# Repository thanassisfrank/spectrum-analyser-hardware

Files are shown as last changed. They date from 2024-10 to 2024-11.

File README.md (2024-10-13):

# 5.8GHz Spectrum analyser hardware

This is an open source project to create a device for analysing the 5.8GHz radio band using the RX5808 analog receiver module and the ESP32-C3 Zero. This repository holds the hardware for the device created with KiCad. For an overview of the firmware, please see *firmware repo*.

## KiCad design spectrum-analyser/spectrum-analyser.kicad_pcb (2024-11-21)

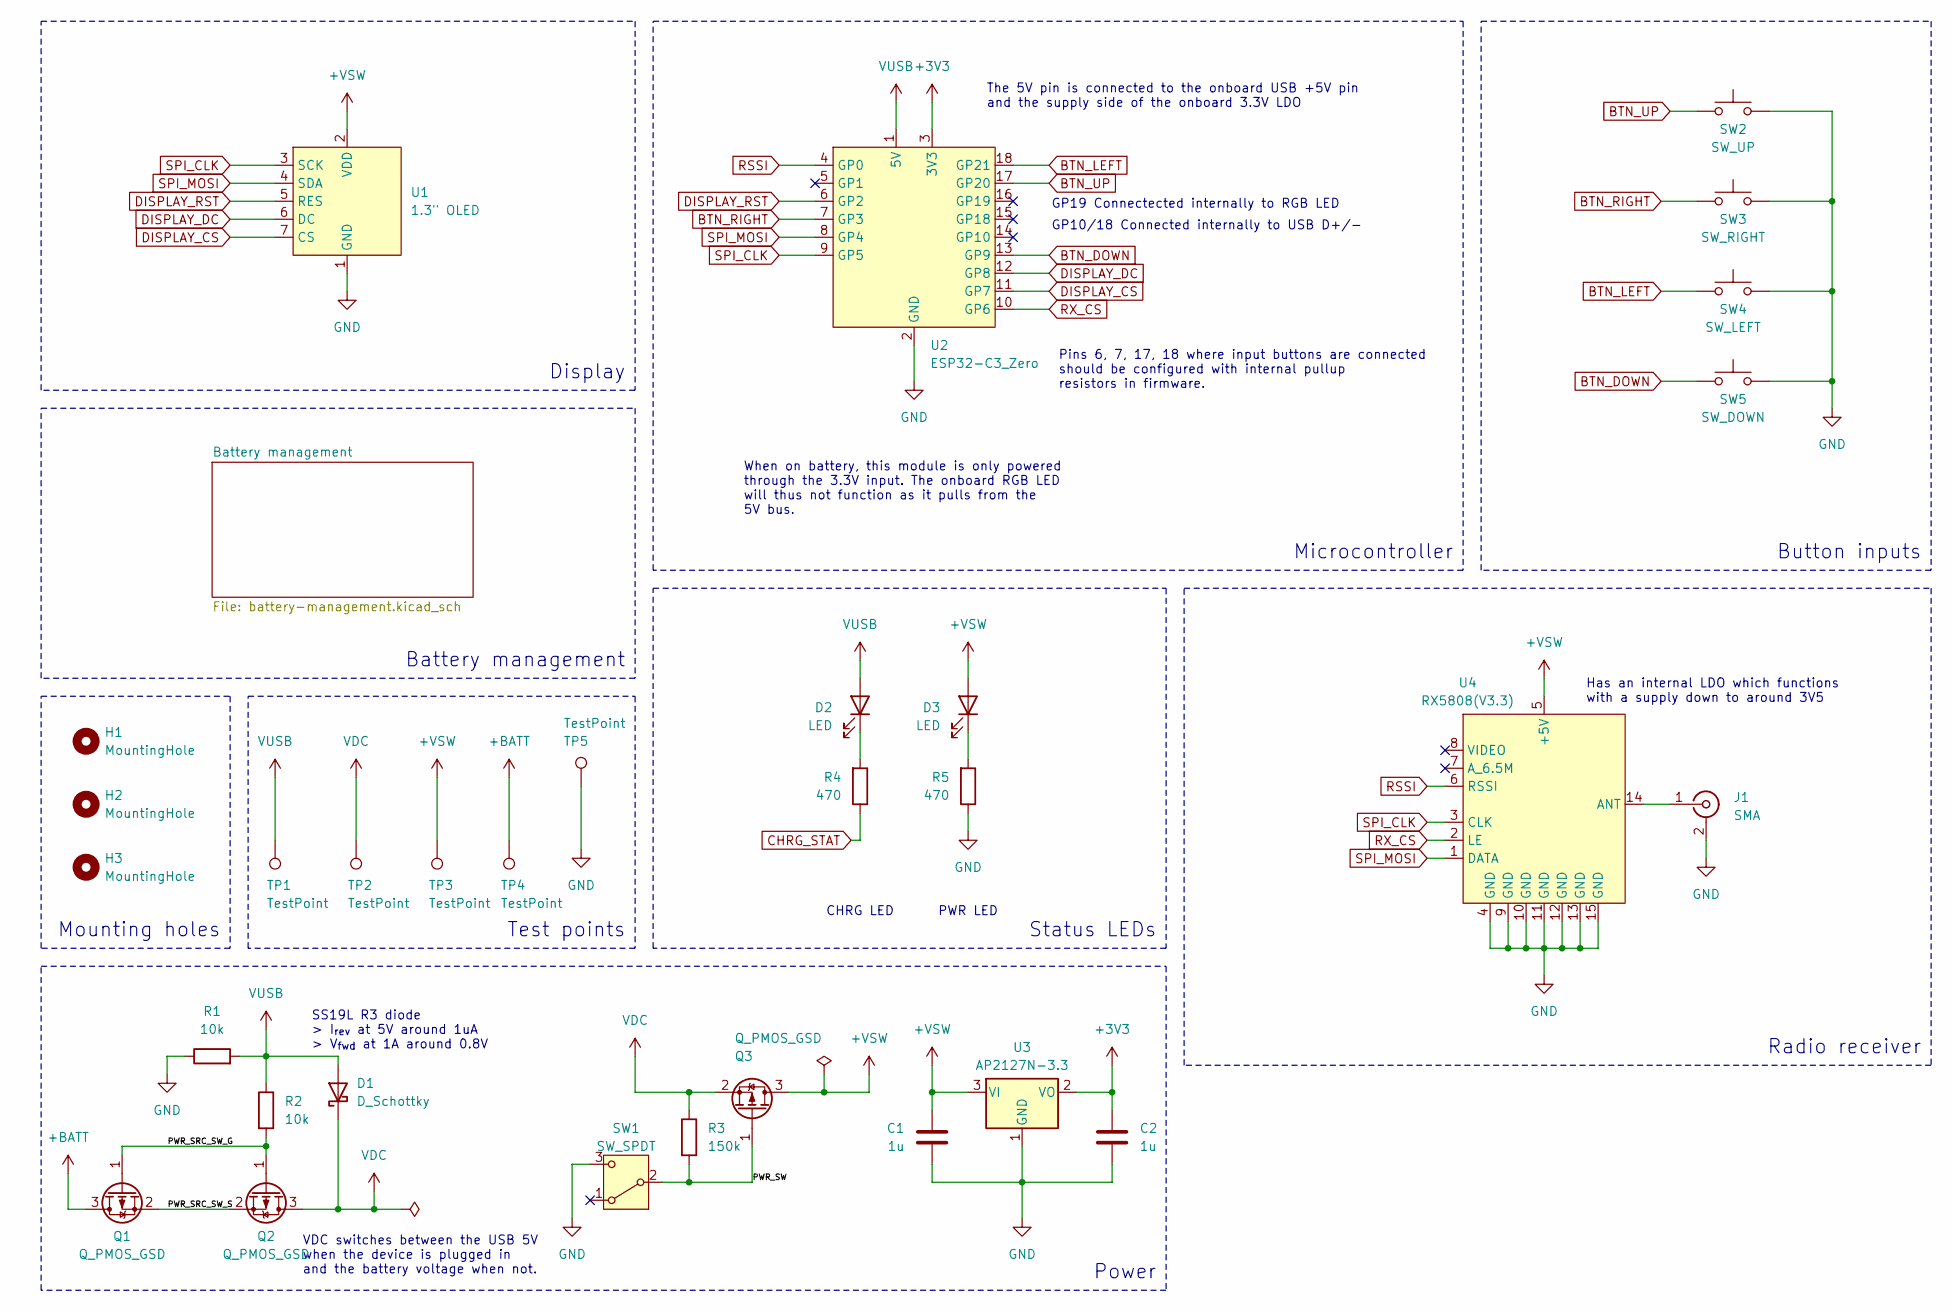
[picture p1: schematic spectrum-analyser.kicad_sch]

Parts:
C1, C2: 1u; C_0603_1608Metric_Pad1.08x0.95mm_HandSolder
D1: D_Schottky; D_SMA_Handsoldering
D2, D3: LED; LED_0603_1608Metric_Pad1.05x0.95mm_HandSolder
H1, H2, H3: MountingHole; MountingHole_3.2mm_M3_ISO7380
J1: SMA; SMA_Samtec_SMA-J-P-H-ST-EM1_EdgeMount
Q1, Q2, Q3: Q_PMOS_GSD; SOT-23
R1, R2: 10k; R_0603_1608Metric_Pad0.98x0.95mm_HandSolder
R3: 150k; R_0603_1608Metric_Pad0.98x0.95mm_HandSolder
R4, R5: 470; R_0603_1608Metric_Pad0.98x0.95mm_HandSolder
SW1: SW_SPDT; SW_SPDT_TEC_1825232-1
SW2: SW_UP; SW_PUSH_ADAFRUIT_SMALL
SW3: SW_RIGHT; SW_PUSH_ADAFRUIT_SMALL
SW4: SW_LEFT; SW_PUSH_ADAFRUIT_SMALL
SW5: SW_DOWN; SW_PUSH_ADAFRUIT_SMALL
TP1, TP2, TP3, TP4: TestPoint; TestPoint_Pad_D2.0mm
TP5: TestPoint; TestPoint_THTPad_D2.0mm_Drill1.0mm
U1: 1.3" OLED; 1.30 OLED
U2: ESP32-C3_Zero
U3: AP2127N-3.3; SOT-23
U4: RX5808(V3.3)

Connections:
+3V3: C2.1, U2.3 (3V3), U3.2 (VO)
+BATT: Q1.3 (D), TP4.1; also elsewhere on the board
+VSW: C1.1, D3.2 (A), Q3.3 (D), TP3.1, U1.2 (VDD), U3.3 (VI), U4.5 (+5V)
/PWR_SRC_SW_G: Q1.1 (G), Q2.1 (G), R2.2
/PWR_SRC_SW_S: Q1.2 (S), Q2.2 (S)
/PWR_SW: Q3.1 (G), R3.2, SW1.2 (B)
BTN_DOWN: SW5.1, U2.13 (GP9)
BTN_LEFT: SW4.1, U2.18 (GP21)
BTN_RIGHT: SW3.1, U2.7 (GP3)
BTN_UP: SW2.1, U2.17 (GP20)
CHRG_STAT: R4.1; also elsewhere on the board
DISPLAY_CS: U1.7 (CS), U2.11 (GP7)
DISPLAY_DC: U1.6 (DC), U2.12 (GP8)
DISPLAY_RST: U1.5 (RES), U2.6 (GP2)
GND: C1.2, C2.2, J1.2 (Ext), R1.1, R5.1, SW1.3 (C), SW2.2, SW3.2, SW4.2, SW5.2, TP5.1, U1.1 (GND), U2.2 (GND), U3.1 (GND), U4.4 (GND), U4.9 (GND), U4.10 (GND), U4.11 (GND), U4.12 (GND), U4.13 (GND), U4.15 (GND); also elsewhere on the board
unnamed: D2.1 (K), R4.2
unnamed: D3.1 (K), R5.2
unnamed: J1.1 (In), U4.14 (ANT)
RSSI: U2.4 (GP0), U4.6 (RSSI)
RX_CS: U2.10 (GP6), U4.2 (LE)
SPI_CLK: U1.3 (SCK), U2.9 (GP5), U4.3 (CLK)
SPI_MOSI: U1.4 (SDA), U2.8 (GP4), U4.1 (DATA)
VDC: D1.1 (K), Q2.3 (D), Q3.2 (S), R3.1, TP2.1
VUSB: D1.2 (A), D2.2 (A), R1.2, R2.1, TP1.1, U2.1 (5V); also elsewhere on the board

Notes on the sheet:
VDC switches between the USB 5V when the device is plugged in and the battery voltage when not.
Power
PWR LED
GP10/18 Connected internally to USB D+/-
Pins 6, 7, 17, 18 where input buttons are connected should be configured with internal pullup resistors in firmware.
When on battery, this module is only powered through the 3.3V input. The onboard RGB LED will thus not function as it pulls from the 5V bus.
Button inputs
Status LEDs
Has an internal LDO which functions with a supply down to around 3V5
Battery management
GP19 Connectected internally to RGB LED
Radio receiver
Test points
Microcontroller
The 5V pin is connected to the onboard USB +5V pin and the supply side of the onboard 3.3V LDO
SS19L R3 diode > I_{rev} at 5V around 1uA > V_{fwd} at 1A around 0.8V
CHRG LED
Mounting holes
Display

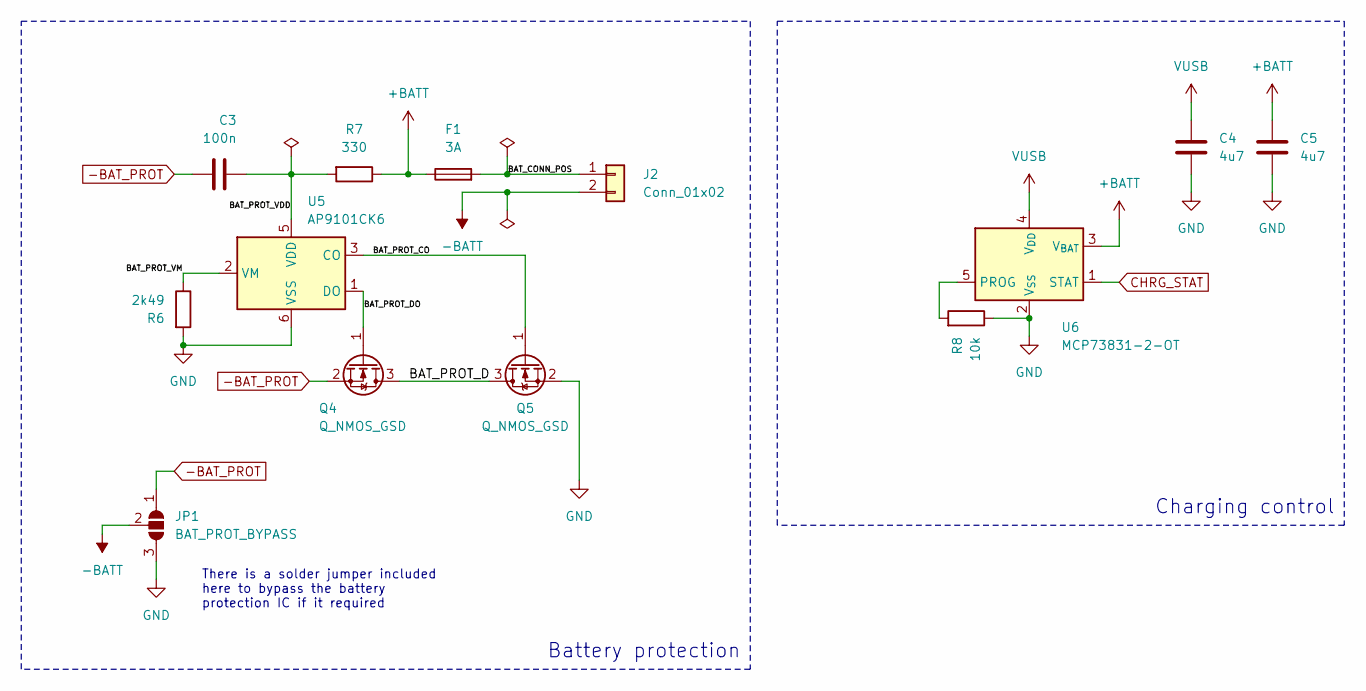
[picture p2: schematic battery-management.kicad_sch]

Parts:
C3: 100n; C_0603_1608Metric_Pad1.08x0.95mm_HandSolder
C4, C5: 4u7; C_0603_1608Metric_Pad1.08x0.95mm_HandSolder
F1: 3A; Fuse_0603_1608Metric_Pad1.05x0.95mm_HandSolder
J2: Conn_01x02; PinHeader_1x02_P2.54mm_Vertical
JP1: BAT_PROT_BYPASS; SolderJumper-3_P1.3mm_Open_RoundedPad1.0x1.5mm
Q4, Q5: Q_NMOS_GSD; SOT-23
R6: 2k49; R_0603_1608Metric_Pad0.98x0.95mm_HandSolder
R7: 330; R_0603_1608Metric_Pad0.98x0.95mm_HandSolder
R8: 10k; R_0603_1608Metric_Pad0.98x0.95mm_HandSolder
U5: AP9101CK6; SOT-23-6
U6: MCP73831-2-OT; SOT-23-5

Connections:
+BATT: C5.1, F1.1, R7.1, U6.3 (V_{BAT}); also elsewhere on the board
-BATT: J2.2, JP1.2 (C)
-BAT_PROT: C3.1, JP1.1 (A), Q4.2 (S)
/Battery management/BAT_CONN_POS: F1.2, J2.1
/Battery management/BAT_PROT_CO: Q5.1 (G), U5.3 (CO)
/Battery management/BAT_PROT_D: Q4.3 (D), Q5.3 (D)
/Battery management/BAT_PROT_DO: Q4.1 (G), U5.1 (DO)
/Battery management/BAT_PROT_VDD: C3.2, R7.2, U5.5 (VDD)
/Battery management/BAT_PROT_VM: R6.1, U5.2 (VM)
CHRG_STAT: U6.1 (STAT); also elsewhere on the board
GND: C4.2, C5.2, JP1.3 (B), Q5.2 (S), R6.2, R8.1, U5.6 (VSS), U6.2 (V_{SS}); also elsewhere on the board
unnamed: R8.2, U6.5 (PROG)
VUSB: C4.1, U6.4 (V_{DD}); also elsewhere on the board

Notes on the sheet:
Charging control
There is a solder jumper included here to bypass the battery protection IC if it required
Battery protection

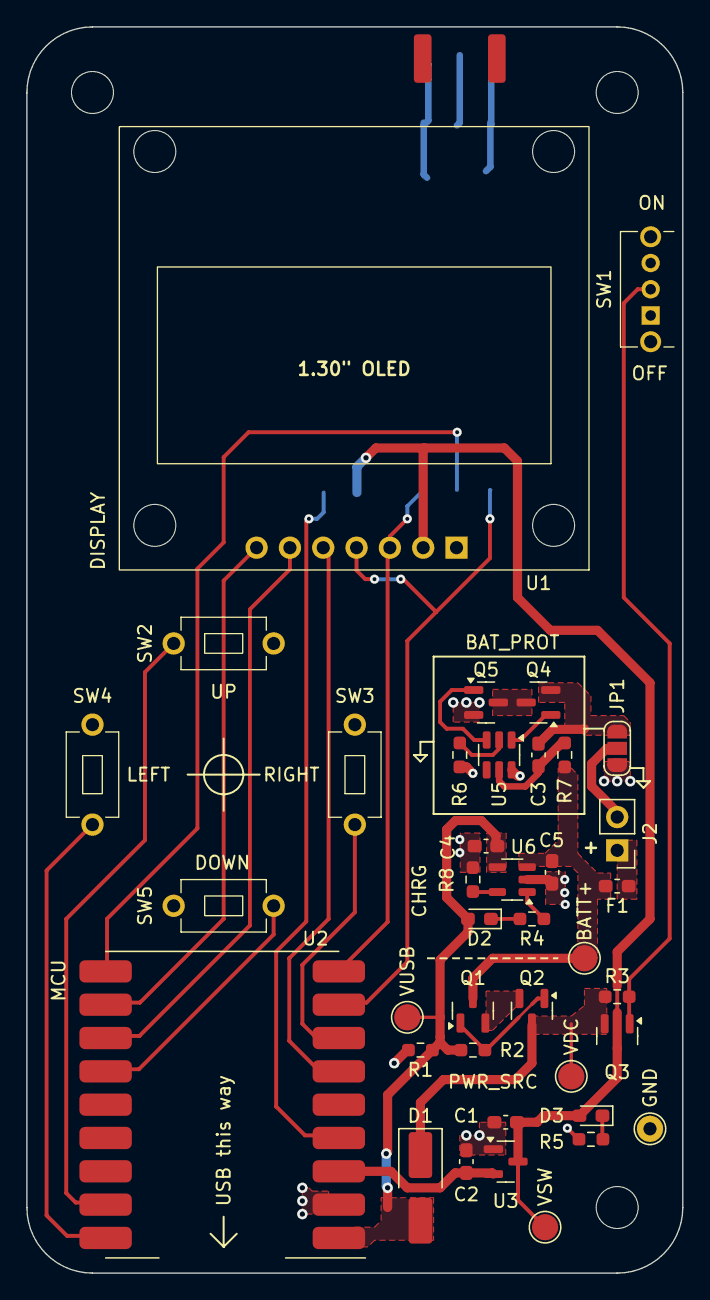
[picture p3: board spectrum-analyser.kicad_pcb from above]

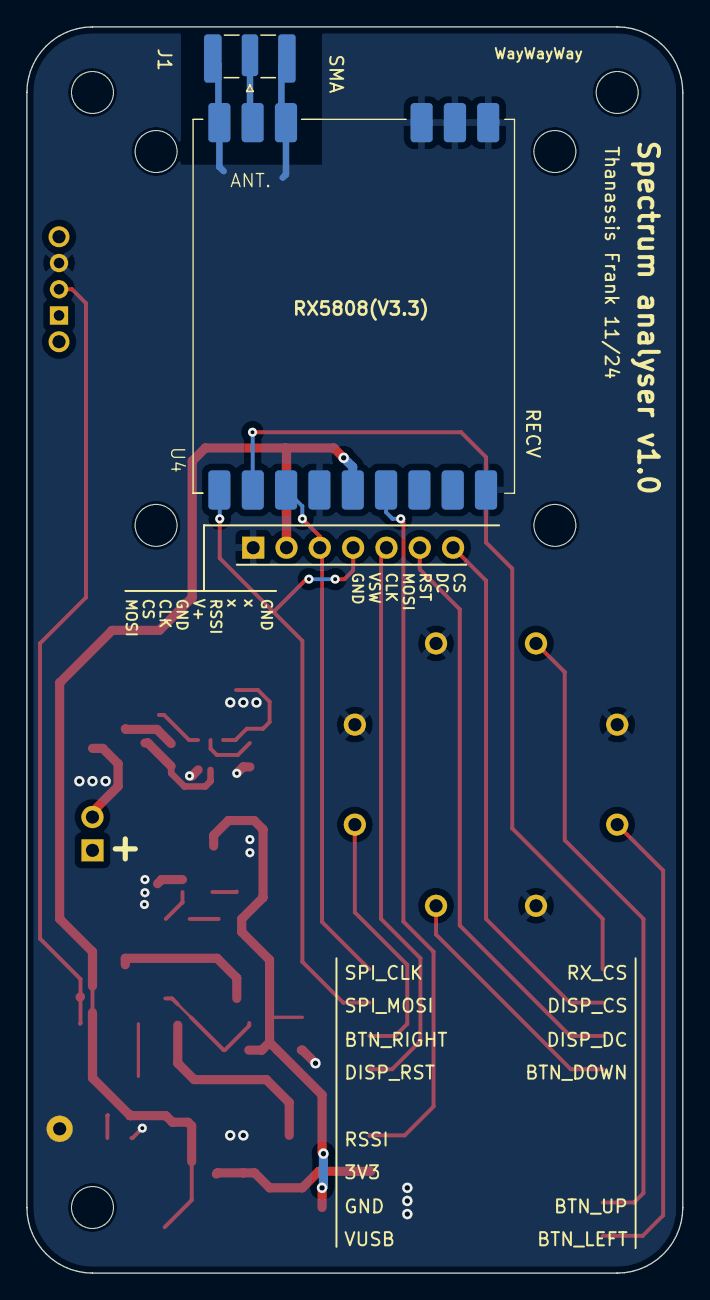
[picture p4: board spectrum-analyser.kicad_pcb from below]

Board: 2 copper layers, 50.0 x 95.0 mm, 44 parts (2 on the bottom side), 33 nets.

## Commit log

2024-10-16 Create KiCad files
    [spectrum-analyser.kicad_pcb, spectrum-analyser.kicad_sch]
2024-10-16 Format schematic sheet
    [spectrum-analyser.kicad_sch]
2024-10-18 Add power and battery charge management to schematic
    [spectrum-analyser.kicad_sch]
2024-10-20 Add battery protection and modify power delivery
    [battery-management.kicad_sch, spectrum-analyser.kicad_sch]
2024-10-26 Assign component footprints
    [battery-management.kicad_sch, spectrum-analyser.kicad_sch]
2024-10-27 Start initial PCB layout
    [battery-management.kicad_sch, spectrum-analyser.kicad_pcb, spectrum-analyser.kicad_sch]
2024-10-27 Improve PCB layout
    [battery-management.kicad_sch, spectrum-analyser.kicad_pcb, spectrum-analyser.kicad_sch]
2024-10-28 Add mounting holes
    [spectrum-analyser.kicad_pcb, spectrum-analyser.kicad_sch]
2024-10-28 Improve component layout for spacing and round mechanical positions
    [spectrum-analyser.kicad_pcb]
2024-10-30 Modify layout to group power and battery, increase board length by 5mm
    [spectrum-analyser.kicad_pcb]
2024-11-06 Add GND keepout around SMA and adjust thermal relief spoke angle for RX module
    [spectrum-analyser.kicad_pcb]
2024-11-10 Route the power management sections
    [spectrum-analyser.kicad_pcb]
2024-11-10 Route signal traces and adjust mcu module pin assignment
    [spectrum-analyser.kicad_pcb, spectrum-analyser.kicad_sch]
2024-11-18 Add informational silkscreen and change 3v3 LDO package
    [battery-management.kicad_sch, spectrum-analyser.kicad_pcb, spectrum-analyser.kicad_sch]
2024-11-19 Assign component values and add charger capacitors
    [battery-management.kicad_sch, spectrum-analyser.kicad_pcb, spectrum-analyser.kicad_sch]
2024-11-20 Re-organise battery management sections
    [battery-management.kicad_sch, spectrum-analyser.kicad_pcb]
2024-11-20 Polish silkscreen and power switch layout
    [spectrum-analyser.kicad_pcb]
2024-11-21 Adjust button placement
    [spectrum-analyser.kicad_pcb]
2024-11-21 Add Batt+ test point
    [spectrum-analyser.kicad_pcb, spectrum-analyser.kicad_sch]
2024-11-21 Generate manufacturing files
    [spectrum-analyser-B_Cu.gbr, spectrum-analyser-B_Mask.gbr, spectrum-analyser-B_Paste.gbr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]
